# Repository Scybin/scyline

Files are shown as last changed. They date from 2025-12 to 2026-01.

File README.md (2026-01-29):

# chitin

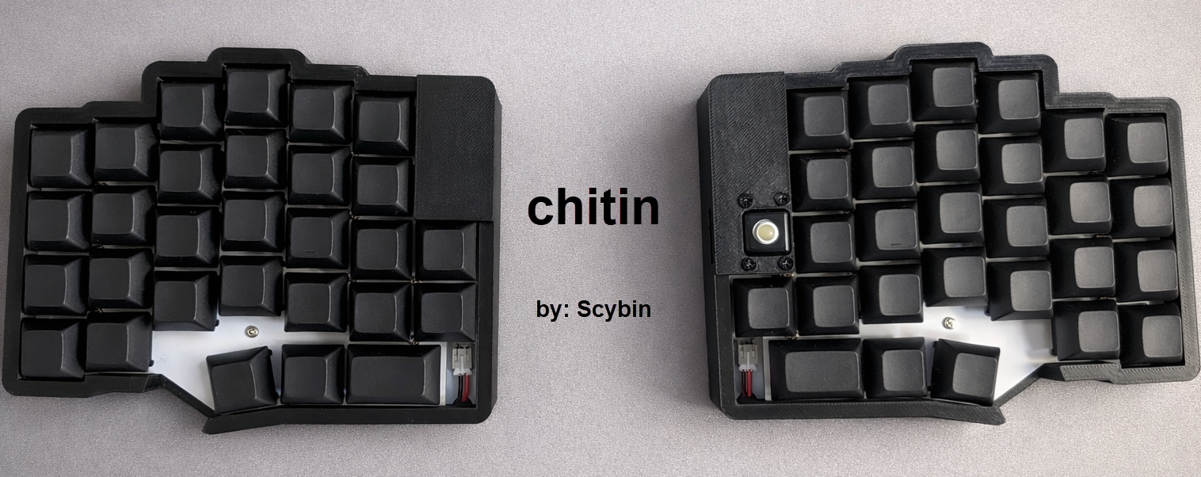
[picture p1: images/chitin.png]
chitin


## 📚 Table of Contents

- [⚠️ Disclaimer](#disclaimer)
- [⌨️ Welcome](#welcome)
- [⚙️ Features](#features)
- [📊 Project Status](#project-status)
- [📦 Parts List](#parts-list)
- [🛠️ Build Guide](#build-guide)
- [💾 Firmware](#firmware)
- [📄 License](#license)

## ⚠️ Disclaimer

This project has reached the fully working prototype stage. All core features have been tested and function as intended. However, as with any DIY hardware project, you should carefully review all files before manufacturing or assembly. The author(s) cannot guarantee flawless operation in every environment or configuration.

The author(s) take no responsibility for any damage, issues, or legal trouble that might result from using this project (see the license). Be sure to follow local laws regarding radio frequencies and DIY electronics.

## ⌨️ Welcome

Chitin is a custom, open-source mechanical keyboard designed for ergonomic comfort, wireless functionality, and trackball. The design is built off my original keyboard design: scyboard, a minimal keyboard design.

## ⚙️ Features

- Ergonomic ortholinear layout
- ZMK firmware support
- USB-C connectivity & battery charging
- Bluetooth compatible
- Customizable keymaps, layers, and macros
- Trackball which can be programmed as a pointing device
- Layout is declared using Ergogen
- KiCad traces auto-routed using Freerouting
- Open source

## 📊 Project Status

The prototype design is complete. Waiting for hardware to build keyboard.

## 📦 Parts List

*I am not sponsored or affiliated with the vendors linked below. This is where I prefer to purchase my products.*

| Part | Quantity | Description | Purchase Link | Datasheet |
|---|---|---|--- |---|
| Microcontroller | 2 | nice!nano v2.0 | [Nice Keyboarrds nice!nano v2.0](https://typeractive.xyz/products/no-solder-spring-headers?variant=47196312502503) | [Nordic nRF52840](https://nicekeyboards.com/nice-nano) | 
| Pin Headers | 4 | Controller socketing system (4mm) | [MAC8 spring-loaded pin headers](https://www.littlekeyboards.com/products/spring-header-12-pin?variant=40197938675779) | [MAC8 spring-loaded pin headers specifications](https://www.mac8sdk.co.jp/uploads/entry_meta/file_value/1117/mac8_2018a_jp-xb2.pdf) |
| Reset Button | 2 | Panasonic miniature momentary button | [Panasonic Reset Button](https://typeractive.xyz/products/reset-button) | [EVQPUC02K](https://cdn.shopify.com/s/files/1/0618/5674/3655/files/PANASONIC-EVQPUC02K.pdf) |
| Power Switch | 2 | Alps miniature SPDT switch | [ALPS Powr Switch](https://typeractive.xyz/products/power-switch) | [SSSS811101](https://cdn.shopify.com/s/files/1/0618/5674/3655/files/ALPS-SSSS811101.pdf) |
| Battery Connector | 2 | JST PH 2.0mm | [JST Battery Jack](https://typeractive.xyz/products/battery-jack) | [JST_PH_S2B-PH-K_1x02_P2.00mm_Horizontal](http://www.jst-mfg.com/product/pdf/eng/ePH.pdf) |
| Battery | 2 | 3.7V LiPo 1200mAh (w/ JST adapter) | [Lithium Ion Polymer Battery - 3.7v 1200mAh](https://www.adafruit.com/product/258) | [301230](https://cdn-shop.adafruit.com/product-files/258/C101-_Li-Polymer_503562_1200mAh_3.7V_with_PCM_APPROVED_8.18.pdf) |
| Diode | 57 | SMD Diode | [Semtech SMD Diodes](https://typeractive.xyz/products/smd-diodes) | [SOD-123](https://www.onsemi.com/download/data-sheet/pdf/mmsd301t1-d.pdf) 									 |
| Hotswap Socket | 57 | Kailh MX PCB Socket | [Kailh Hotswap Sockets](https://typeractive.xyz/products/hotswap-sockets) | [CPG151101S11](https://www.kailhswitch.com/Content/upload/pdf/202215927/CPG151101S11-16.pdf?rnd=181) |
| MX Switch | 57 | JWICK Linear Switches | [JWK JWICK Linear Switches](https://typeractive.xyz/products/jwk-jwick-linear-switches) | [MX Series Keyswitch](https://cdn.sparkfun.com/datasheets/Components/Switches/MX%20Series.pdf) |
| MX Keycap | 57 | 55 x 1u, 2 x 1.5u | [DSA Keycaps](https://typeractive.xyz/products/dsa-keycaps) | [DSA Keycap Project](https://drive.google.com/drive/folders/0B0LNjZf_tzjWZGhwZ0VKUm9PQVE?resourcekey=0-rYUAMYD1-22Btlgdmpb0IQ) |
| M2x15 Standoff | 18 | Standoffs for plate | [Newark M2x15 Standoff](https://www.newark.com/wurth-elektronik/970150244/standoff-brass-hex-f-f-m2-15mm/dp/46AJ4338)  | [Farnell Datasheet](https://www.farnell.com/cad/3209262.pdf) |
| M2x5e Screw | 8 | Screws to connect bottom case to top case | [CO-RODE Screw Kit](https://www.amazon.com/gp/product/B01FTI8TM8/) | |
| M2x6 Screw | 18 | Screws for bottom case and top plate | [CO-RODE Screw Kit](https://www.amazon.com/gp/product/B01FTI8TM8/) | |
| M2.5x8 Screw | 4 | Screws to hold trackball in top case | [CO-RODE Screw Kit](https://www.amazon.com/gp/product/B01FTI8TM8/) | |
| M2x3 Insert Nut | 8 | Inserts for top cases | [uxcell Knurled Insert Nuts](https://www.amazon.com/dp/B07LBQFNQD?th=1) | |
| M2.5x2 Nut | 4 | Nuts to hold trackball in top case | [Newark M2.5 Hex Nuts](https://www.newark.com/tr-fastenings/m2-5-hfst-z100/full-nut-steel-bzp-m2-5/dp/53M8595) | [Farnell Datasheet](https://www.farnell.com/datasheets/2644739.pdf) |
| Trackball Breakout | 1 | Pimoroni RGBW Trackball Breakout | [Trackball Breakout by Pimoroni](https://shop.pimoroni.com/products/trackball-breakout?variant=27672765038675) | [Trackball Dimensions](https://cdn.shopify.com/s/files/1/0174/1800/files/trackballbreakout.png?v=1599645804) |
| Qwiic Connector | 1 | JST SH 4-pin Right Angle Connector | [JST SH 4-pin Right Angle Connector (10-pack) - Qwiic Compatible](https://www.adafruit.com/product/4208) | [KAWEEI TECHNOLOGY 1.0MM WAFER 90 SMT TYPE REEL PACKAGE](https://cdn-shop.adafruit.com/product-files/4208/4208_Kaweei_C13396_diagram.pdf) |
| Bottom Case | 2 | 3D printed bottom case | [Case Files Found Here](https://github.com/Scybin/chitin/tree/master/3d) | |
| Top Case | 2 | 3D printed top case (tb case for trackball) | [Case Files Found Here](https://github.com/Scybin/chitin/tree/master/3d) | | 

**NOTE: The trackball replaces the position of 1 switch from the keyboard layout. If not incorporating a trackball in the build, add 1 quantity to each of the following parts:**
- Diode
- Hotswap Socket
- MX Switch
- 1u MX Keycap

## 🛠️ Build Guide

TODO

## 💾 Firmware

To get started, I recommend forking my personal repository for chitin here: [zmk-config-chitin](https://github.com/Scybin/zmk-config-chitin). Making modifications to the keyboard can be done within the config folder. To flash the keyboard, follow the flashing instructions in the [ZMK docs](https://zmk.dev/docs).

My build sets the central device to the right half of the keyboard, and the peripheral to the left half. Making changes to which half the trackball resides on, or excluding the trackball from the build requires many changes to the code in the chitin repository and source module.

The repository uses my chitin ZMK module here: [zmk-keyboard-chitin](https://github.com/Scybin/zmk-keyboard-chitin), and my Pimoroni trackball driver module (derived from mwandzik's driver) here: [zmk-driver-pim447](https://github.com/Scybin/zmk-driver-pim447).

## 📄 License

This project is licensed under the MIT License. See the [LICENSE](LICENSE) file for details.

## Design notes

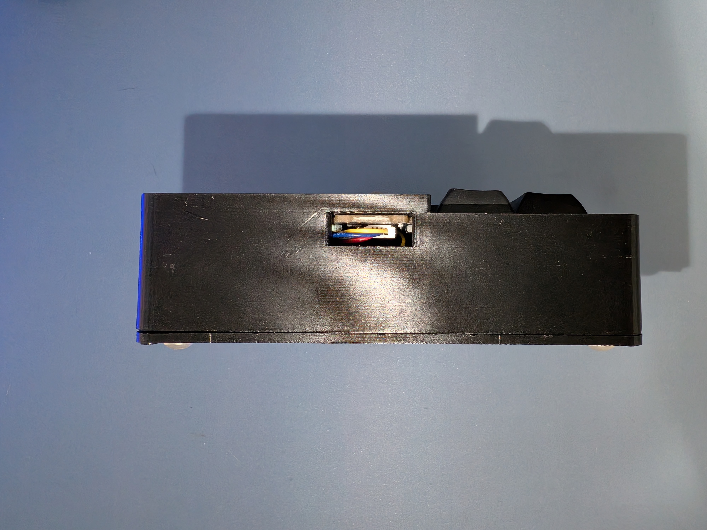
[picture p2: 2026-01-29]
images/chitin_side.jpg

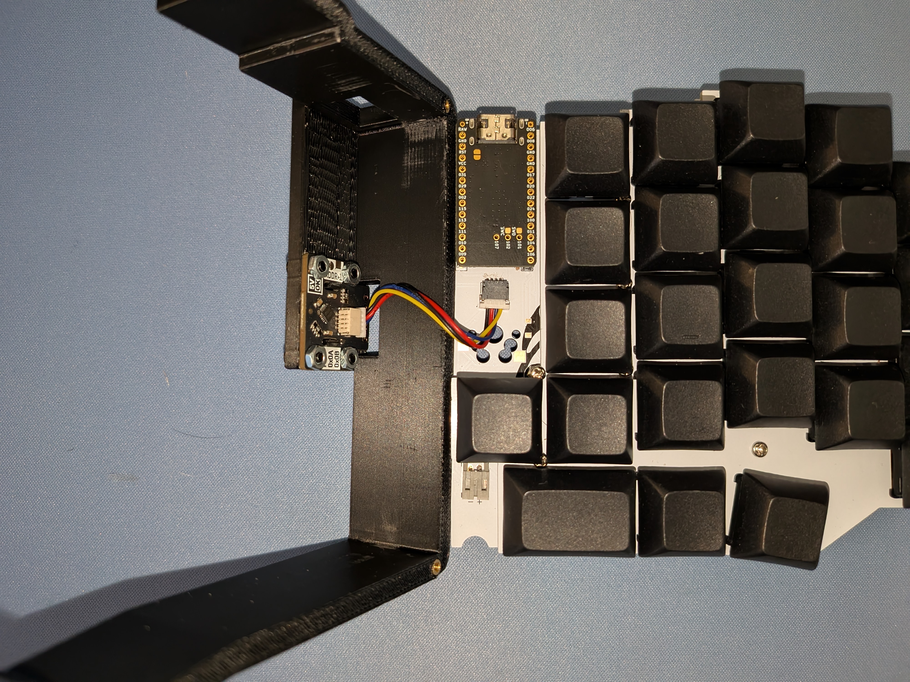
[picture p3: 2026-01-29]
images/chitin_top_open.jpg

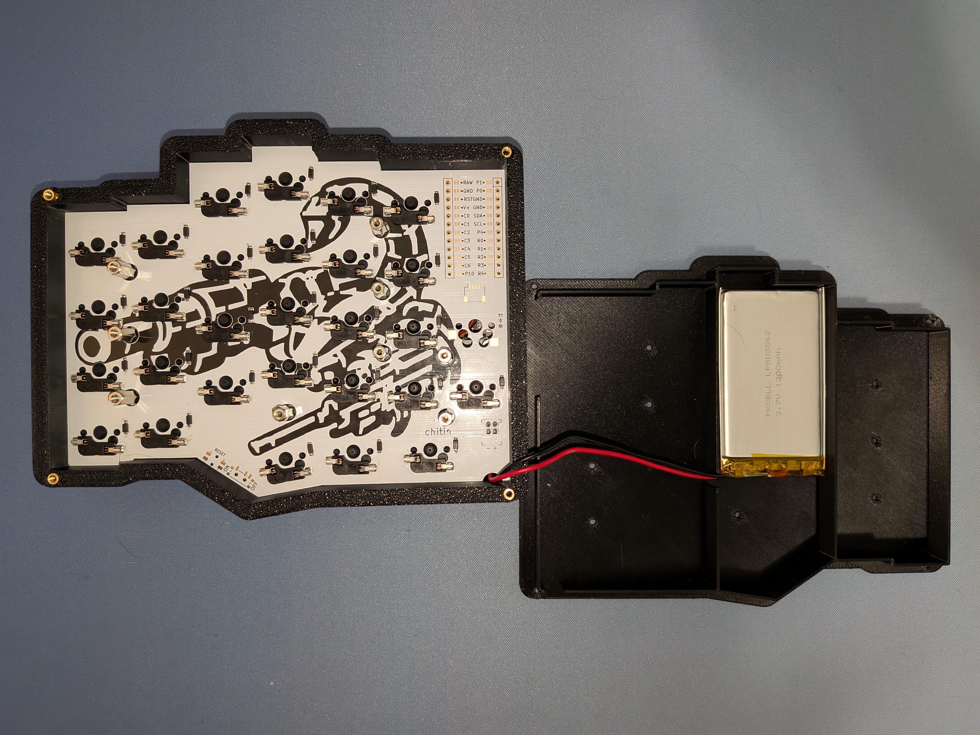
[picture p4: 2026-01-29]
images/chitin_bottom_open.jpg

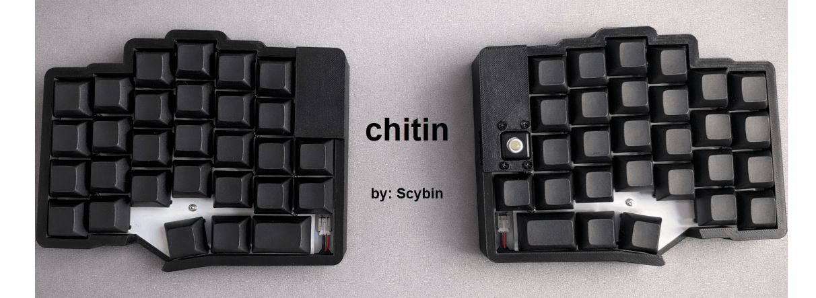
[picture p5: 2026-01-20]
images/chitin_cropped.png

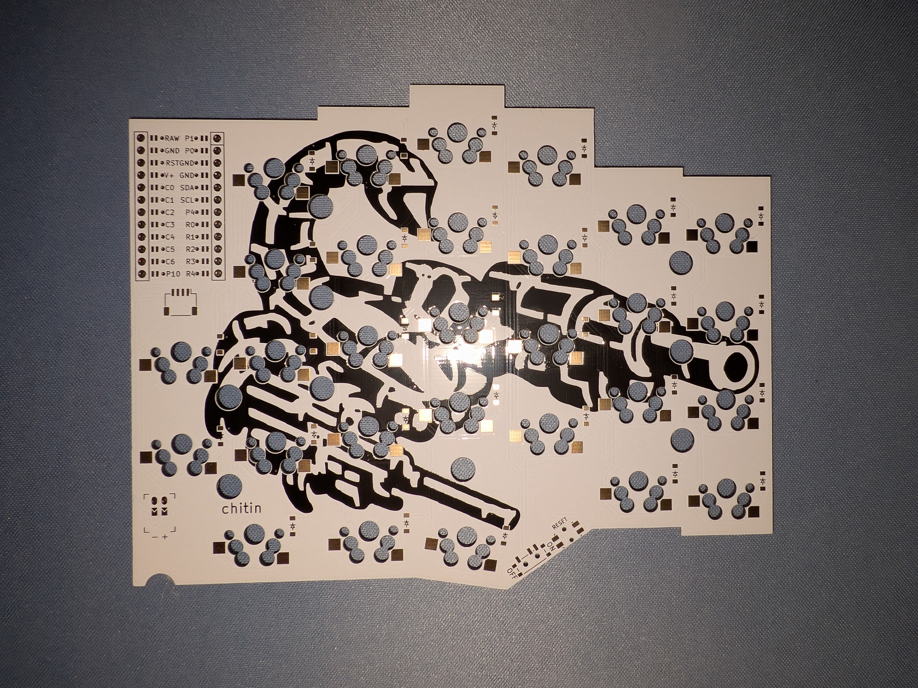
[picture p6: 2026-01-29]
images/chitin_pcb.jpg

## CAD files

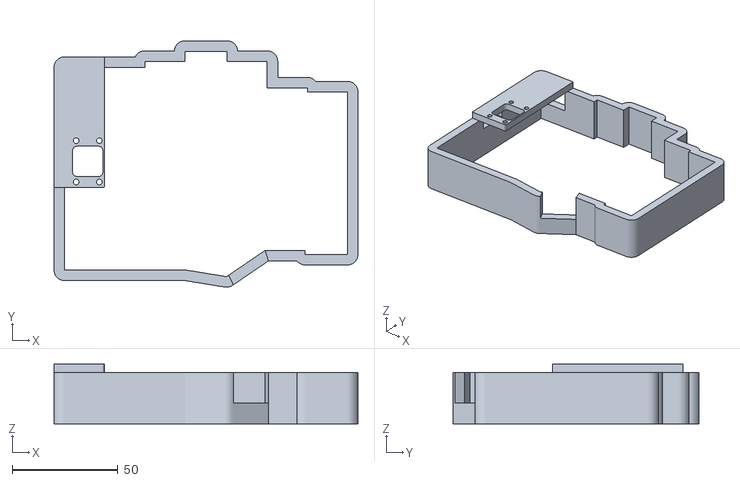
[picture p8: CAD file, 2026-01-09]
3d/top_case_tb_R.stl
144.0 x 116.7 x 28.3

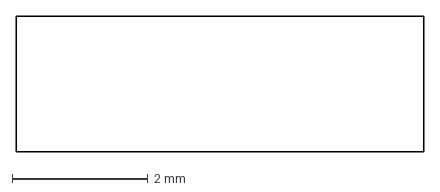
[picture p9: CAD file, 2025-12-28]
ergogen/build/outlines/bottom_lip_rect_R.dxf
6.00 x 2.00 mm

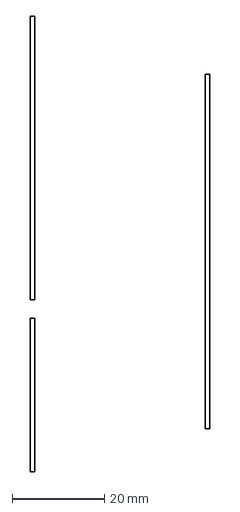
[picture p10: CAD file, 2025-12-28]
ergogen/build/outlines/inner_lip_R.dxf
39.0 x 98.8 mm

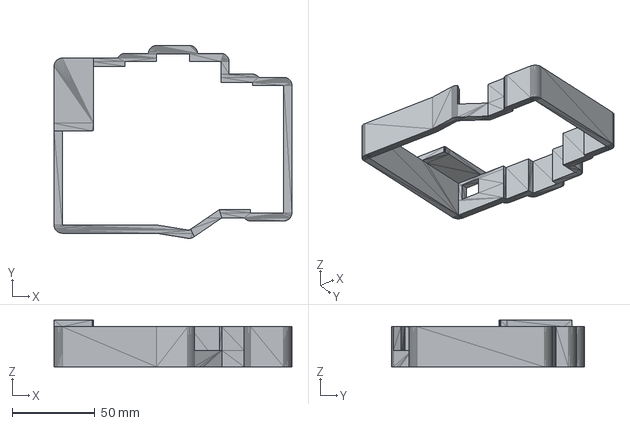
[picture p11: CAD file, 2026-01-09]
3d/top_case_R.step
144.0 x 116.7 x 28.3 mm

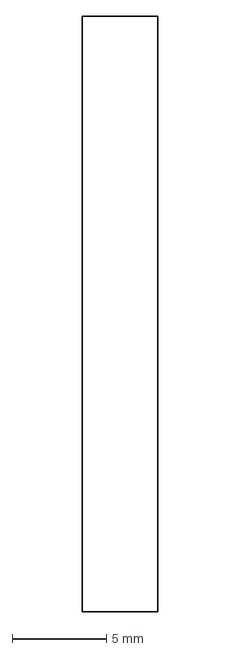
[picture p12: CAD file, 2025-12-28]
ergogen/build/outlines/mcu_lip_clear_R.dxf
4.00 x 31.6 mm

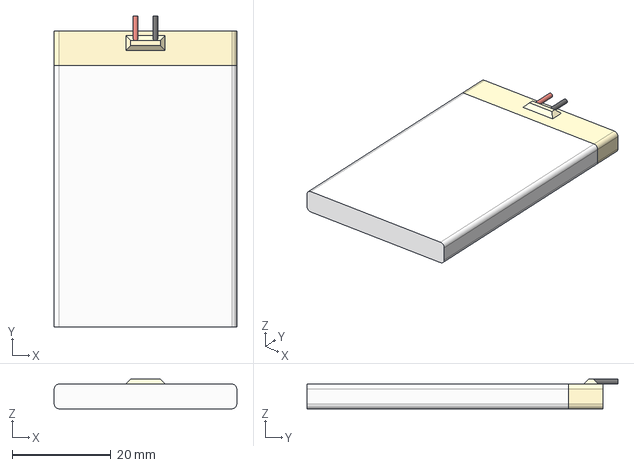
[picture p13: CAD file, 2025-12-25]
kicad/3d_models/258 1200mAh lipo.step
37.0 x 63.0 x 6.00 mm

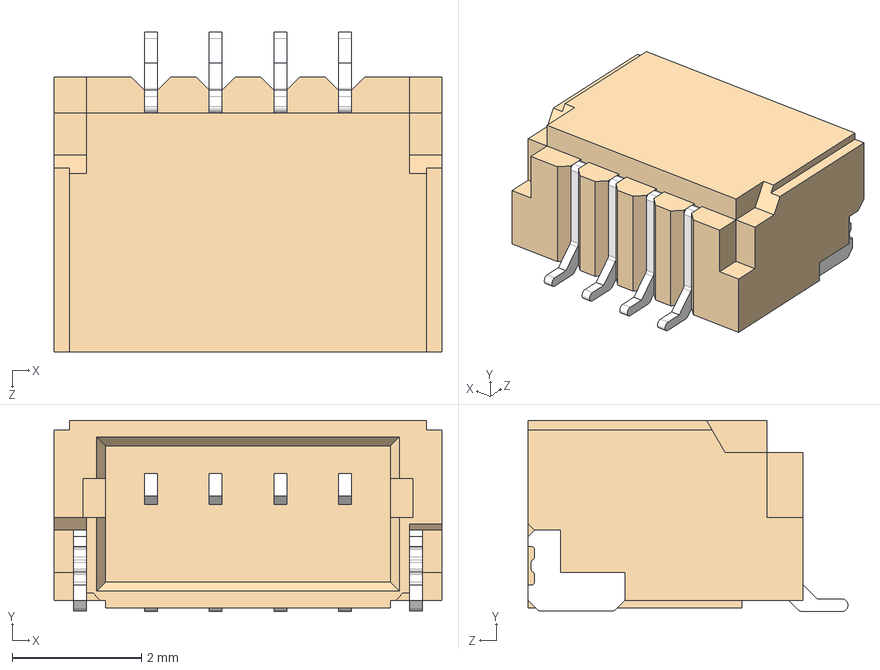
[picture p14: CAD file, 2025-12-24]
kicad/3d_models/SM04B-SRSS-TB_LF__SN_.stp
6.00 x 2.96 x 4.95 mm

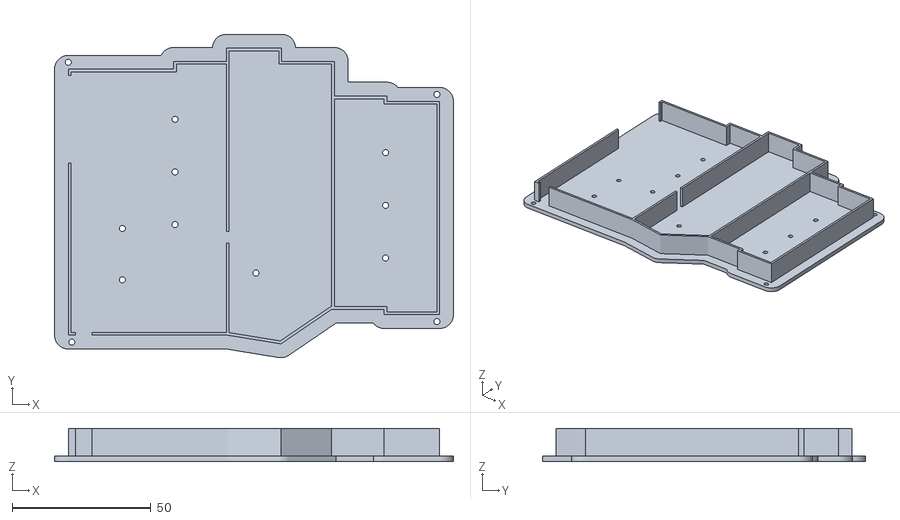
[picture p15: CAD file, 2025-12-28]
3d/bottom_case_R.stl
144.0 x 116.7 x 12.0

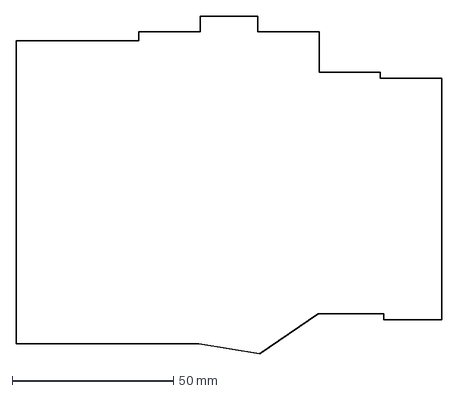
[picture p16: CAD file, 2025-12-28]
ergogen/build/outlines/bottom_lip_cut_R.dxf
132.0 x 104.7 mm

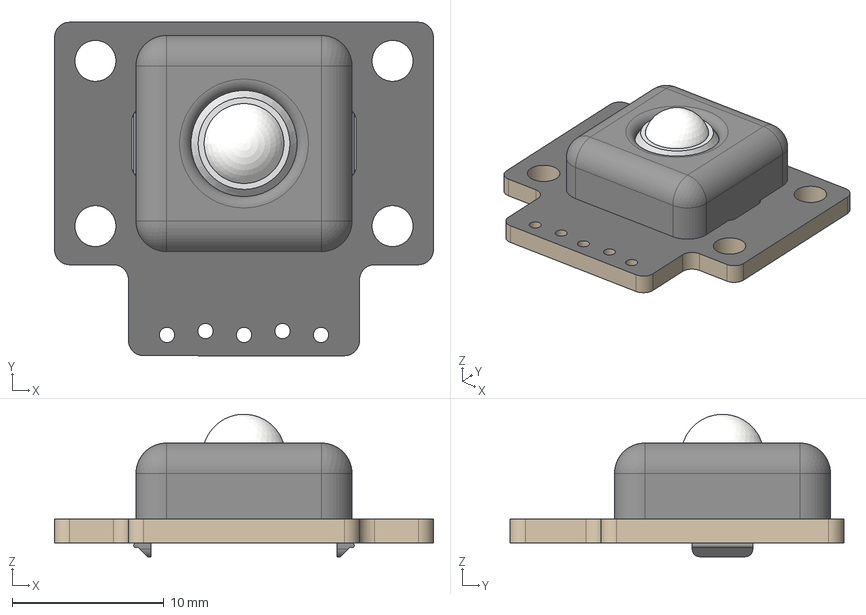
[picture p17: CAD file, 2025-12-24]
kicad/3d_models/PIM447.step
25.0 x 22.0 x 9.40 mm
PIM447 PCB
Cover
Shroud

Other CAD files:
3d/bambu_petg_model/top_case_tb_L.gcode.3mf
3d/bambu_petg_model/top_case_tb_R.gcode.3mf
3d/top_case_tb_L.stl
3d/bambu_petg_model/top_case_R.gcode.3mf
3d/bambu_petg_model/top_case_L.gcode.3mf
3d/top_case_L.step
3d/bambu_petg_model/chitin_switchplate_case_tb.gcode.3mf
3d/bambu_petg_model/chitin_switchplate_case.gcode.3mf
3d/bambu_petg_model/chitin_bottom_case_L.gcode.3mf
3d/bambu_petg_model/chitin_bottom_case_R.gcode.3mf
3d/bottom_case_L.stl
3d/case.step
3d/switchplate_case.stl
3d/switchplate_case_tb.stl
3d/top_case_L.stl
3d/top_case_R.stl
3d/wall_cover_case_tb_L.step
ergogen/build/outlines/bottom_lip_cut_L.dxf
ergogen/build/outlines/bottom_lip_rect_L.dxf
ergogen/build/outlines/bottom_lip_rect_raise_L.dxf
ergogen/build/outlines/bottom_lip_wall_L.dxf
ergogen/build/outlines/bottom_lip_wall_R.dxf
ergogen/build/outlines/button_access_L.dxf
ergogen/build/outlines/button_access_R.dxf
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

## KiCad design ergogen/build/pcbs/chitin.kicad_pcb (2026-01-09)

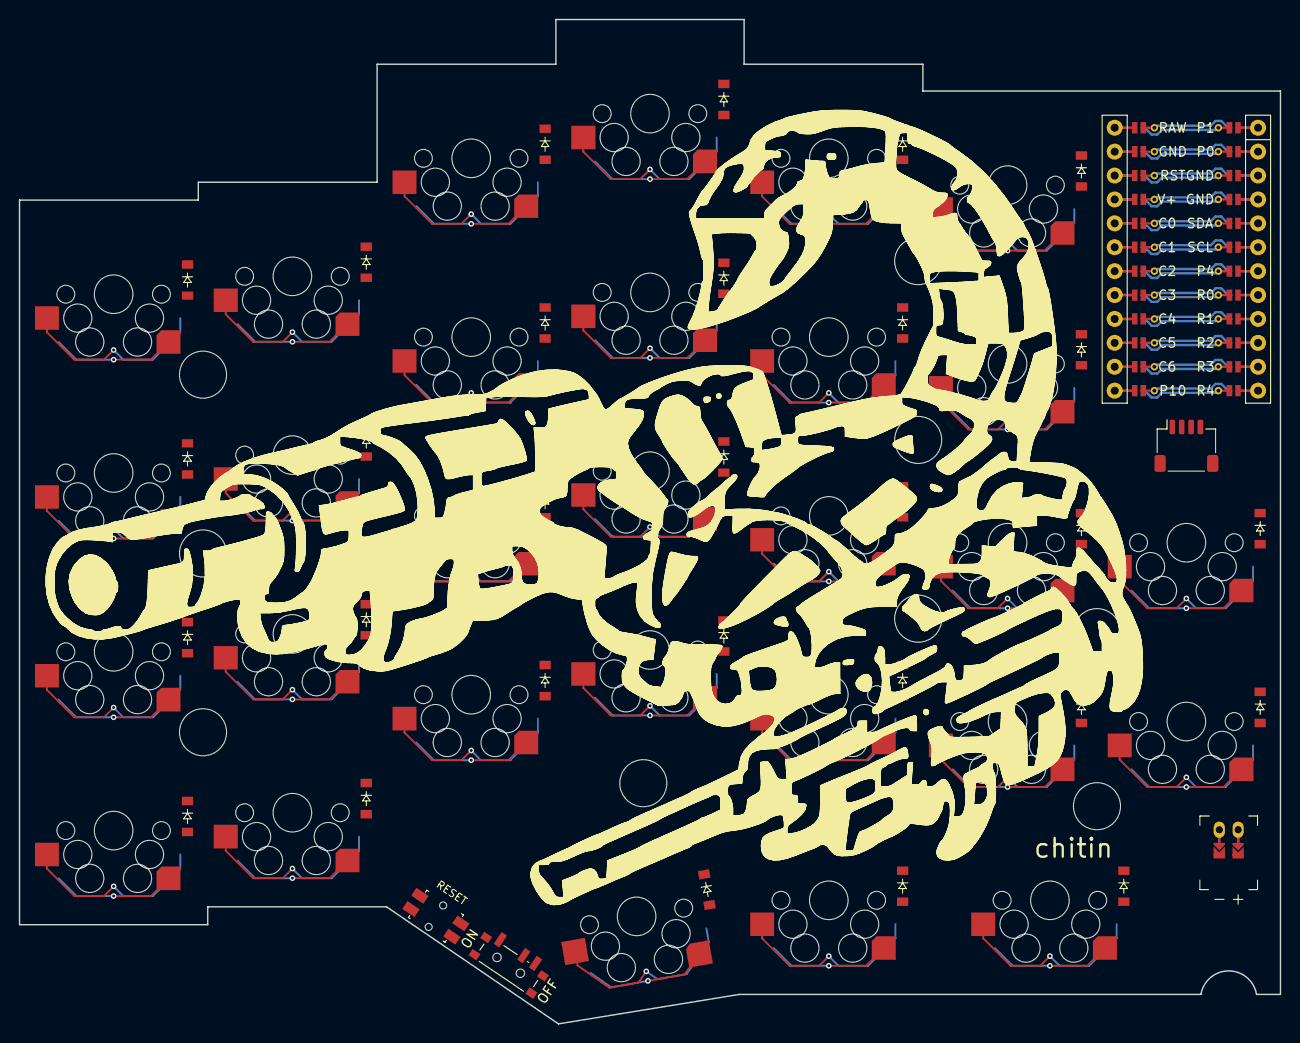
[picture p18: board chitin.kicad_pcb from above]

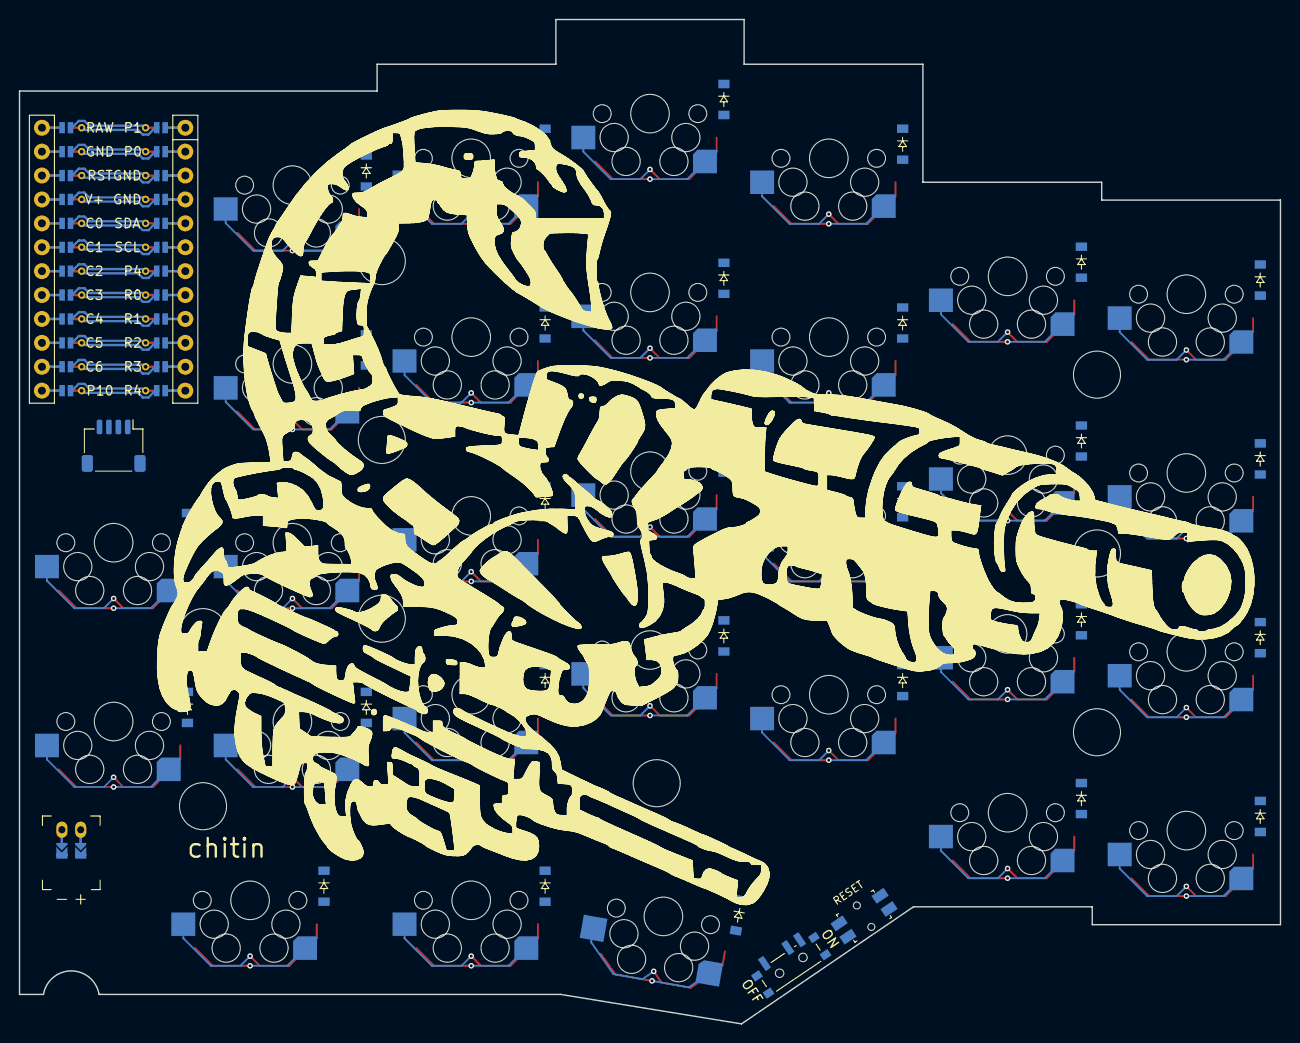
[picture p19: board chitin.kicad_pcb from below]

Board: 2 copper layers, 134.0 x 106.7 mm, 102 parts (58 on the bottom side), 50 nets.

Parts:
D1, D2, D3, D4, D5, D6, D7, D8, D9, D10, D11, D12, D13, D14, D15, D16, D17, D18, D19, D20, D21, D22, D23, D24, D25, D26, D27, D28, D29, D30, D31, D32, D33, D34, D35, D36, D37, D38, D39, D40, D41, D42, D43, D44, D45, D46, D47, D48, D49, D50, D51, D52, D53, D54, D55, D56, D57, D58: diode_tht_sod123
J1: qwiik_jst
JST1: battery_connector_jst_ph_2
LOGO1: logo_dual_chitin
MCU1: mcu_nice_nano
MH1, MH2, MH3, MH4, MH5, MH6, MH7, MH8, MH9: mounting_hole_npth
PWR1: power_switch_smd_side
RST1: reset_switch_smd_side
S1, S2, S3, S4, S5, S6, S7, S8, S9, S10, S11, S12, S13, S14, S15, S16, S17, S18, S19, S20, S21, S22, S23, S24, S25, S26, S27, S28, S29: switch_mx

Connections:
BAT_P: JST1.1, PWR1.1, PWR1.3
C0: MCU1.120, S1.1, S2.1, S3.1, S4.1
C1: MCU1.119, S5.1, S6.1, S7.1, S8.1
C2: MCU1.118, S9.1, S10.1, S11.1, S12.1, S25.1
C3: MCU1.117, S13.1, S14.1, S15.1, S16.1, S26.1
C4: MCU1.116, S17.1, S18.1, S19.1, S20.1, S27.1
C5: MCU1.115, S21.1, S22.1, S23.1, S24.1
C6: MCU1.114, S28.1, S29.1
GND: J1.1, JST1.2, MCU1.103, MCU1.104, MCU1.123, RST1.1, RST1.3
JST1_1: JST1.11, JST1.21, JST1.31
JST1_2: JST1.12, JST1.22, JST1.32
R0: D4.1, D8.1, D12.1, D16.1, D20.1, D24.1, D33.1, D37.1, D41.1, D45.1, D49.1, D53.1, MCU1.108
R1: D3.1, D7.1, D11.1, D15.1, D19.1, D23.1, D32.1, D36.1, D40.1, D44.1, D48.1, D52.1, MCU1.109
R2: D2.1, D6.1, D10.1, D14.1, D18.1, D22.1, D29.1, D31.1, D35.1, D39.1, D43.1, D47.1, D51.1, D58.1, MCU1.110
R3: D1.1, D5.1, D9.1, D13.1, D17.1, D21.1, D28.1, D30.1, D34.1, D38.1, D42.1, D46.1, D50.1, D57.1, MCU1.111
R4: D25.1, D26.1, D27.1, D54.1, D55.1, D56.1, MCU1.112
RAW: MCU1.124, PWR1.2
RST: MCU1.122, RST1.2, RST1.4
SCL: J1.4, MCU1.106
SDA: J1.3, MCU1.105
V+: J1.2, MCU1.121
index_bottom_B: D17.2, D46.2, S17.2
index_home_B: D18.2, D47.2, S18.2
index_top_B: D20.2, D49.2, S20.2
index_upper_B: D19.2, D48.2, S19.2
inner_bottom_B: D21.2, D50.2, S21.2
inner_home_B: D22.2, D51.2, S22.2
inner_top_B: D24.2, D53.2, S24.2
inner_upper_B: D23.2, D52.2, S23.2
layer_cluster_B: D26.2, D55.2, S26.2
macro_bottom_B: D28.2, D57.2, S28.2
macro_home_B: D29.2, D58.2, S29.2
middle_bottom_B: D13.2, D42.2, S13.2
middle_home_B: D14.2, D43.2, S14.2
middle_top_B: D16.2, D45.2, S16.2
middle_upper_B: D15.2, D44.2, S15.2
outer_bottom_B: D1.2, D30.2, S1.2
outer_home_B: D2.2, D31.2, S2.2
outer_top_B: D4.2, D33.2, S4.2
outer_upper_B: D3.2, D32.2, S3.2
pinky_bottom_B: D5.2, D34.2, S5.2
pinky_home_B: D6.2, D35.2, S6.2
pinky_top_B: D8.2, D37.2, S8.2
pinky_upper_B: D7.2, D36.2, S7.2
ring_bottom_B: D9.2, D38.2, S9.2
ring_home_B: D10.2, D39.2, S10.2
ring_top_B: D12.2, D41.2, S12.2
ring_upper_B: D11.2, D40.2, S11.2
space_cluster_B: D27.2, D56.2, S27.2
tuck_cluster_B: D25.2, D54.2, S25.2

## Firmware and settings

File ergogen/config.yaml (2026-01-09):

meta:
  engine: 4.2.1
  name: chitin
  version: 1.0
  author: Scybin
  url: https://github.com/Scybin/chitin

units:

  # Key Variables
  kx: u # 19mm spacing between key centers
  ky: u # 19mm spacing between key centers
  kcow: 14 # MX plate cutout width
  kcoh: 14 # MX plate cutout height
  keycw: 18 # keycap width (MX 18 mm)
  keych: 18 # keycap height (MX 18 mm)
  switch_rotation: 180 # Hotswap south
  pcb_shift: 1 # PCB outline padding

  # Diode Variables
  vertical_diode_shift: 1.5 # Shift to avoid overlap (y)
  horizontal_diode_shift: -0.5 kcow - 0.85 # Shift to avoid overlap (x)
  diode_rotation: -90 # Diode rotation
  diode_padding_y: 1.5 # Vertical padding between diodes
  diode_downshift_y: 0.25 # Shift paired diodes on y-axis

  # Controller Variables
  mcu_width: 18 # x-axis
  mcu_height: 30.6 # y-axis
  mcu_padding_y: 1
  mcu_padding_x: 1.5

  # Reset Switch Variables
  rst_x: 27.884 # Reset switch position on x-axis
  rst_y: -28.5 # Reset switch position on y-axis

  # On Off Switch Variables
  pwr_x: 27.725 # On off switch position on x-axis
  pwr_y: rst_y-9.35 # On off switch position on y-axis
  pwr_shift: 5 # On off switch footprint center point shift

  # JST-PH Variables
  jst_x: pwr_x-4.5 # JST connector position on x-axis
  jst_y: -34.01 # JST connector position on y-axis
  jst_shift: 3.5 # JST footprint center point shift

  # Screw variables
  screw_hole_m2: 1.1 # M2 screw hole radius
  screw_hole_m2_5: 1.35  # M2.5 screw hole radius

  # Standoff variables
  insert_size: 2.5 # Threaded screw inserts 3.2mm wide, and 3mm tall
  insert_radius: 1.25 # Threaded screw insert radius
  spacer_radius: 2.5 # M2 hex standoffs
  spacer_diameter: spacer_radius * 2

  # FR4 variables
  fr4_thickness: 1.6  # standard FR4 thickness in mm

  # Case variables
  case_x: kx+8 # Case position on x-axis
  case_y: ky+8 # Case position on y-axis
  wall_z: 24.3 # Wall height (& cut)
  cover_z: 28.3 # Cover height (& fill)
  lip_z: 12 # Bottom / Inner lip height

  # Trackball variables
  trackball_housing_w: 14 # Square Width
  trackball_housing_h: 14 # Square Height
  trackball_clearance: 0.15 # Padding
  trackball_hole_w: trackball_housing_w + 2*trackball_clearance
  trackball_hole_h: trackball_housing_h + 2*trackball_clearance
  trackball_offset_x: 0.5kx + (mcu_width + mcu_padding_x)/2 - 1.25
  trackball_offset_y: 3.5
  trackball_screw_x: 5.5
  trackball_screw_y: 9.8

points:
  zones:

    # Main key matrix
    matrix:
      key:
        padding: ky
        spread: kx
        tags:
          - key
          - matrix_key
      anchor.shift: [100,-150] # Fix KiCad placement
      columns:
        outer:
          key:
            column_net: C0
        pinky:
          key:
            column_net: C1
            stagger: 0.1ky
        ring:
          key:
            column_net: C2
            stagger: 0.66ky
        middle:
          key:
            column_net: C3
            stagger: 0.25ky
        index:
          key:
            column_net: C4
            stagger: -0.25ky
        inner:
          key:
            column_net: C5
            stagger: -0.15ky
      rows:
        bottom:
          row_net: R3
        home:
          row_net: R2
        upper:
          row_net: R1
        top:
          row_net: R0
          key:
            tags:

    # Thumb cluster
    thumb:
      key:
        padding: ky
        spread: kx
        tags:
          - key
          - thumb_key
      anchor:
        ref: matrix_index_bottom
      columns:
        tuck:
          key:
            column_net: C2
            name: thumb_tuck
            shift: [-1.075kx, -1.24ky]
            rotate: 10
        layer: 
          key:
            column_net: C3
            name: thumb_layer
            shift: [-1kx, -1.15ky]
        space:
          key:
            column_net: C4
            name: thumb_space
            width: 1.5kx
            shift: [-14.5, -1.15ky]
      rows:
        cluster:
          row_net: R4

    # Extra Keys
    extra:
      key:
        padding: ky
        spread: kx
        tags:
          - key
          - extra_key
      anchor:
        ref: matrix_inner_bottom
        shift: [kx, 0]
      columns:
        macro:
          key:
            column_net: C6
      rows:
        bottom:
          row_net: R3
          name: extra_bottom
        home:
          row_net: R2
          name: extra_top
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

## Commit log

2025-12-18 Add ceoloide footprints
2025-12-18 Generate Ergogen output
    [button_access.dxf, button_wall.dxf, combo.dxf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]
2025-12-18 Add 3d models
    [Diode_SOD-123.step, Hotswap_MX.step, MX_1.00u_CAD.step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]
2025-12-18 Add kicad 3d models
    [Diode_SOD-123.step, Hotswap_MX.step, MX_1.00u_CAD.step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]
2025-12-19 Refactor JST variables and adjust extrude values
    Updated variable names for JST connectors and adjusted extrude values for switchplate and walls.
2025-12-20 Add exclusion
    [bottom_case.stl, case.stl]
2025-12-20 Remove extra files
    [bottom_case.stl]
2025-12-24 Refactor config variables and add insert points
    Updated variable names for clarity and added new insert points.
2025-12-24 Update shifts and extrusions in config.yaml
2025-12-24 Add notch for JST PH wires in config.yaml
    Added notch for JST PH wires in config.
2025-12-24 Add PCB notch configuration to config.yaml
2025-12-24 Modify plate_hole and full_case definitions
    Updated plate_hole configuration and modified full_case structure.
2025-12-24 Define bottom lip wall and cut in config.yaml
    Added bottom lip wall and cut definitions to the config.
2025-12-27 Add ergogen-footprints submodule
2025-12-27 Add scybin-footprints submodule
2025-12-27 Add scybin footprints
2025-12-27 Track scybin footprints as regular files
2025-12-27 Rename kicad 3d library
2025-12-28 Finalize PCB with Freerouting
    [chitin.kicad_pcb]
2025-12-28 Generate gerbers
    [chitin.kicad_pcb]
2025-12-28 Add 3d print models
    [chitin_bottom_case_L.gcode.3mf, chitin_bottom_case_R.gcode.3mf, chitin_switchplate_case.gcode.3mf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]
2025-12-28 Rename case files
    [chitin_top_case_L.gcode.3mf, chitin_top_case_R.gcode.3mf, chitin_top_case_tb_L.gcode.3mf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]
2026-01-09 Update case holes
2026-01-09 Update case files for increased hole sizes
    [chitin.kicad_pcb, chitin_top_case_L.gcode.3mf, chitin_top_case_R.gcode.3mf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]
